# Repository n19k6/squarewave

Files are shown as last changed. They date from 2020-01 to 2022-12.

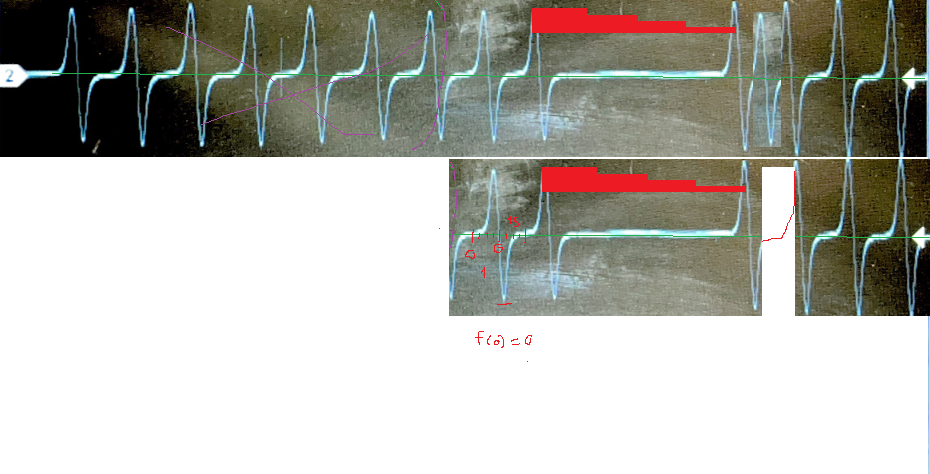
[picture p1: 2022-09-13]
v11_honda_v1/02_signal_synthesis/quadradic_1.png

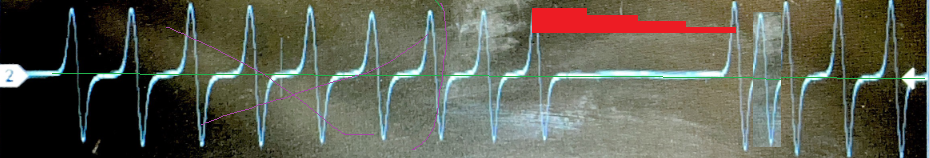
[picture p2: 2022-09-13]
v11_honda_v1/02_signal_synthesis/quadradic_0.png

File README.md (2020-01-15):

# squarewave

This repository contains information about generating squarewave signals using arduino hardware via bit-banging using interrupts.

The original motivation was to simulate a signal generated by a rotational-speed sensor.

The following diagram shows the signal sequence generated by one rotation:

```
 +---+   +---+   +---+   +--     -+   +---+   +---+                  
 |   |   |   |   |   |   |   ...  |   |   |   |   |
 +   +---+   +---+   +---+        +---+   +---+   +---+---+---+---+---

 1       2       3       4            61      62      63      64
```
 
As you can see the signal value high is triggered 62 times followed by a short pause.

The initial requirement was that the signal frequency should be as high as to simulate 7000 rotations measured by the rotational-speed sensor.
We denote this frequency as wheel frequency. Since one rotation generates a signal containing 64 sections the signal frequency is 64 times higher.

The microcontroller ATmega328P contained on the Arduino Nano V3 has three hardware timers capable to generate PWM signals.
But since the signal we want to generate contains a pause at the end of each rotation of the wheel we have to modify the signal PWM signal in some way.
We are using an interrupt to change the signal values 0/1 which is triggered by a hardware timer at the appropriate frequency.
 
Since timer 1 is a 16-bit timer which is counting at 16 Mhz (with prescaler set to 1) it takes 4096 us (4096 microseconds = (1/16 MHz)*2^16) to trigger an overflow.
You can define a compare register to trigger an interrupt if the counter has reached a specific value, i.e. you can trigger at any interval between 1/16 MHz and 4096 us.

Since the calculation and setting of the output pin which is done in an interrupt service routine needs some amount of cpu cylcles the frequency of the interrupts can not be close to 16 MHz.

The calculation of the signal can be done using the following pseudo code using a global volatile byte typed variable count:

```
 +---+   +---+   +---+   +--     -+   +---+   +---+                  
 |   |   |   |   |   |   |   ...  |   |   |   |   |
 +   +---+   +---+   +---+        +---+   +---+   +---+---+---+---+---

 0   1   2   3   4   5   6            120 121 122 123 124 125 126 127

volatile byte count = 0

set counter of timer 1 to 0
if (count % 2 == 0 and count < 124):
  set output to 1
else
  set output to 0
count++
count = count % 128
```

Now the question remains what is the maximum wheel frequency we can achieve, i.e. how much time or cpu cycles does the interrupt service routine use.

If you have a two signal oscilloscope with an appropriate bandwidth, you can measure this by setting a different output pin to 1 at the beginning and 0 at the end of the routine.

We measured that > 160 cpu cycles are necessary. Defining 320 as the minimum for the compare register yields wheel frequencies > 20000 rpm.

## Possible improvements
- FastWrite

## Setup:
If you are using a nano clone with CH340 chip you have to install the driver (see [3]) and use "ATmega328P (Old Bootloader)" as processor within the arduino IDE.

## Structure:
```
README.md - readme (english)
LIESMICH.md - readme (german)
v1_1000_rpm - yields ~ 1000 rpm
v1_maximum - proof of concept that 20000 rpm can be reached
v1_measurement - was used to determine minimum value for compare interrupt
```

Details about timers and interrupts are available at [1].
The used arduino clone "Nano V3.0 CH340" is available at [2].
Install instructions regarding CH320 USB2Serial chip driver are available at [3].

## References:

[1] https://www.heise.de/developer/artikel/Timer-Counter-und-Interrupts-3273309.html (german)

[2] https://www.az-delivery.de/products/nano-v3-0-pro (german)

[3] https://www.makershop.de/ch340-341-usb-installieren/ (german)

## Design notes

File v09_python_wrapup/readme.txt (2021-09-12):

# vim show white spaces
- use commands: set list and set nolist
- to insert a literal tab character use CTRL+V to escape it 
# notepad++ do not replace tab with spaces
- settings -> preferences -> tab settings -> python -> uncheck 'replace by space'

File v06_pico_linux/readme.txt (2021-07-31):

this is an empty file, not exactly it contains in fact two lines
this is line two

let's do it!

https://hackaday.io/project/177817-rp2040-pio-case-study
http://people.ece.cornell.edu/land/courses/ece4760/RP2040/index_rp2040_testing.html

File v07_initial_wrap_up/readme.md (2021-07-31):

# Generating simple waveforms using a raspberry pico and micropython 

(directory location is: v7_initial_wrap_up)

This directory should be used to try to finalize the squarewave project. I.e. more focus on documentation and clean code.

## Requirements

The waveform we want to generate can be thought of being generated by three rotation gears. This might help to memorize the signals we want to generate. The circuit will be used to simulate signals used in the control electronics of a car. The examples given here are generic and can be used to generate arbitrary cyclic signals.

The focus of this write down should be to present how easy it is to generate this signals using a raspberry pico and micropython interaction.

*insert svg here,  IGF, CS, CRKS - camshaft, crankshaft, ignition confirmation signal, Crankshaft Position Sensor (CKP), Camshaft Position Sensor (CMP) todo*

test

Above in the picture you can see three gears. The first gear with a lot of gear tooths can be thought of to generate the *CKP signal* (crankshaft position sensor), the second gear with three gear tooths generates the *CMP signal* (camshaft position sensor) and the third gear with four gear tooths generates the *IGF signal* (ignition confirmation signal). The second and third wheel rotate twice as fast as the first wheel.

You do not have to bother about the abbreviations of the signals - you could also denote the wheels and respective signals A, B, C. Sticking to the abbreviations CKP, CMP and IGF just help me to document my project.

Suppose you put a light sensor at a fixed position that could measure the gear tooths of the rotation wheel passing by. Further on suppose each tooth passing by generates a high signal for 25% and a low signal for 75% of the period of time. So having 34 tooths and 2 gaps in one rotation we can divide the signal corresponding to one rotation into 144 instances in time, e.g. (34+2)\*4. The multiplier corresponds to the 25% percent high state when a tooth passes by. See the following graphical representation:

```
+---+           +---+           +---+           +---+                    +---+           +---+           +---+                                           
|   |           |   |           |   |           |   |            ...     |   |           |   |           |   |                                           
+   +-----------+   +-----------+   +-----------+   +----------       ---+   +-----------+   +-----------+   +-------------------------------------------
0   1   2   3   4   5   6   7   8   9  10  11  12  13  14  15          124 125 126 127 128 129 130 131 132 133 134 135 136 137 138 139 140 141 142 143   
```

The IGF signal generated by the third gear is inverted, i.e. a gear tooth passing by generates a low signal for 25% and a high signal for 75% of the period of time.

## Raspberry Pico Hardware

The raspberry pico has dedicated hardware to accomplish our task. What we use is PIOs () and DMA (?) hardware.
Unfortunately we have to control the DMA hardware by accessing registers directly. There is not API exposed by the rp2 micropython port.

* we construct an array containing the data for all three signals
* we initialize a state machine (PIO) to listen to the FIFO and set the GPIO pins accordingly
* we set up to two DMA channels:
    * the first channel streams the data from  the array to the FIFO of the state machine
    * the second channel is triggered when the first channel has terminated and restarts the first channel again

##  Links

Details about the directory structure:

```
C:.
├─── diagrams/ generate_wheels.py, generate_ascii.py
├─── circuit/ fritzing
├─── source-code/osci
```

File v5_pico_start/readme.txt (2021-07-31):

20210313:

begriffe:

Vx:
alle poties als 32 stellungs poties zu verstehen

V10:
kurbelwelle dreht mit 0,200-20000 U/min 34+2 zacken, duty 25%
nockenwelle 3+4 synchron zu kurbelwelle mit verschiebung
zuendsignal synchron zu kurbelwelle mit verschiebung
zuenaussetzer 1,2,3,4 einzeln komplet aus oder an
wegfahrsperre
zwei lambda sonden signale (=PWM) 0,1 Hz, 1Hz, 10 Hz + duty cyle  = 4 poties

loesungsansaetze:
a) lambda via pwm library
b) andere signale via PIO mit sync oder PIO aus speicher

V11:
zuendaussetzer nicht nur an oder aus sondern aussetzer regelbar von 1/1000 aussetzer bis 1000/1000 aussetzer
frage: per zufall (schwierig?)

V12:
kurbelwelle dreht nicht mit konstanter geschwindigkeit innerhalb einer drehung

###################################

https://www.heise.de/developer/artikel/Ein-Picobello-Microcontroller-Raspberry-Pi-Pico-Board-5045274.html
https://www.cnx-software.com/2021/01/27/a-closer-look-at-raspberry-pi-rp2040-programmable-ios-pio/
https://tutorials-raspberrypi.de/raspberry-pi-pico-mikrocontroller-programmieren/

https://hackspace.raspberrypi.org/articles/what-is-programmable-i-o-on-raspberry-pi-pico
https://www.seeedstudio.com/blog/2021/01/25/programmable-io-with-raspberry-pi-pico/
https://learn.adafruit.com/getting-started-with-raspberry-pi-pico-circuitpython
https://www.cnx-software.com/2021/01/27/a-closer-look-at-raspberry-pi-rp2040-programmable-ios-pio/

MCP3008-I/P

https://www.adafruit.com/product/931
-> nicht verfuegbar
https://shop.pimoroni.com/products/1-12-oled-breakout?variant=29421050757203
-> 14 EUR
https://www.adafruit.com/product/1463
-> 10 EUR
BME280
MPU9250 board
MPU6050 board
-> adafruit 3886-> 7 EUR

Raspberry Pi Pico - USB HID Auto Clicker with Circuit Python

5x2 kabel breadboard 
5x2 femaleXfemale

blues teile breadboard book

20210307:
https://cdn-shop.adafruit.com/datasheets/MCP3008.pdf
https://blog.rareschool.com/2021/02/raspberry-pi-pico-project-2-mcp3008.html

todos:
implement wegfahrsperre
stop and instanciate pio maschine with frequency from poti
research on sync pios, read from memory
document requirements V10+V11+V12
order mcp3008, 10kOhm poties 20, jumper, adapter osci, level shifter ic
#############################
Hi,
I am a PIO beginner. I am exited about the board and got started fast using the good documentation.
I am porting a arduino sketch I programmed month ago for an arduino nano to generate a digital signal using a hardware timer and an ISR.
It did worked but the the hardware was not capable to deliver the signal with the needed frequency, so I thought a good idea to try and get started with the pico.
Especially I like the easy way to do programming with the Thonny IDE, hence no compile cycle or uploading of programs necessary.
My idea is to use micropython for the not time critical parts and use the PIOs for signal generation.

To get started the examples  micropython PIO examples are very valuable: https://github.com/raspberrypi/pico-examples

To understand/use the PIO capabilities it would be great to have two mini examples demonstrating the following:
a) cycle accurate sync of statemachines (see section 3.2.7 Interactions Between State Machines from the rp2040 datasheet: This allows cycle-accurate synchronisation between state machines)
b) reading/consuming data from RAM

The context of my questions is the following: 
I have dump of a signal (on two pins, one clock, one data) that should be triggered if a special input pin goes low (see 20210322c_arduino_reference.png)
I managed to implement the first 25% of the signal with PIO instructions and than reached the mark of 32 instructions, I think with much tinkering I might be able to represent the signal inside the 32 instractions, did only use the X register so far. (see 20210322a.py and 20210322a.png)

Nevertheless if I know/understand cycle-accurate synchronisation between state machines it would be far more straightforward to generate the two synced signals.

Thanks.

Best regards,
Raphael

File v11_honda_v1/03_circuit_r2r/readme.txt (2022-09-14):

dummy

pico: dma 8 outputs using pmod board
check digital outputs first

https://www.hackster.io/56254/using-the-pmod-r2r-with-arduino-uno-ad3de4

0-255 -> 0-3.3V

960 werte pro periode
mem_slot_2[i] = 0b0000_0000_0000_0000_0000_0000_0000_0000
960/4 = 240 32bit words

calculate micropython code for array

-1V = 0, 1V=255

pico+logic analyzer (im keller)

---
pins ansteuern
volt messen (nach wiederstaenden)
ausrechnen (drehzahl 300-mindestens 6.000 besser 10.000)
signal mit oszilaskop messen

---
20220913:
MicroPython v1.16 on 2021-06-18
update to v1.19.1
machine.bootloader()
and copy uf2 file to RPI-RP2
MicroPython v1.19.1 on 2022-06-18

https://vanhunteradams.com/Pico/DAC/DMA_DAC.html
https://forum.micropython.org/viewtopic.php?f=21&t=10717
https://stackoverflow.com/questions/66388451/how-to-use-raspberry-pi-pico-with-dac-with-spi-to-generate-sine-wave-of-1-khz-wi
https://codeutility.org/dma-how-to-use-raspberry-pi-pico-with-dac-with-spi-to-generate-sine-wave-of-1-khz-with-20-k-samples-per-cycle-stack-overflow/
https://people.ece.cornell.edu/land/courses/ece4760/RP2040/index_rp2040_testing.html
https://www.youtube.com/watch?v=OenPIsmKeDI (Raspberry Pi Pico PIO - Ep. 8 - Introduction to DMA)
https://www.youtube.com/watch?v=PrMQpv9iCFw
rp2040-datasheet.pdf DMA section

https://iosoft.blog/2021/10/26/pico-adc-dma/

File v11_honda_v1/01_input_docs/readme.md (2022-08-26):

a)

push: i2s data via dma

https://www.reddit.com/r/raspberrypipico/comments/lcmhs5/got_i2s_dac_working_with_pico/

spi via dma

https://vanhunteradams.com/Pico/DAC/DMA_DAC.html (SPI interface)

https://mcturra2000.wordpress.com/2021/08/09/rp2040-using-dma-to-set-spi-dac-mcp4921/

b)

convert pwm to analog using low filter

https://github.com/romilly/pico-code/blob/master/docs/fungen.md

c) r2r DAC

hardware:

* adafruit circuitpython DAC

https://www.instructables.com/Arbitrary-Wave-Generator-With-the-Raspberry-Pi-Pic/

https://learn.adafruit.com/mcp4725-12-bit-dac-tutorial

https://www.hackster.io/news/learn-how-to-use-pwm-to-generate-an-audio-signal-from-your-raspberry-pi-pico-00347dece8b8

https://github.com/rgrosset/pico-pwm-audio

https://datasheets.raspberrypi.com/rp2040/hardware-design-with-rp2040.pdf#page=24

https://datasheets.raspberrypi.com/rp2040/hardware-design-with-rp2040.pdf#page=24

a) Resistor DAC

https://datasheets.raspberrypi.com/rp2040/hardware-design-with-rp2040.pdf#page=24 (3.2.1. Resistor DAC)

https://digilent.com/reference/_media/reference/pmod/pmodr2r/pmodr2r_sch.pdf

b) Low Passfilter (PWM -> Analog)

https://github.com/romilly/pico-code/blob/master/docs/fungen.md

c) Dedicated DAC

https://datasheets.raspberrypi.com/rp2040/hardware-design-with-rp2040.pdf#page=24 (3.4.2. PCM(I2S audio, PCM5101A) [PCM]

https://github.com/miketeachman/micropython-i2s-examples (I2S DAC)

https://github.com/romilly/pico-code/blob/master/src/pico_code/pico/experiments/pio_dac.py

http://blog.rareschool.com/2021/02/raspberry-pi-pico-simple-projects.html

d) DMA

https://iosoft.blog/category/dma/

Kaufen (boards):

Berrybase:

Adafruit MCP4725 Breakout Board - 12-Bit DAC mit I2C Interface

MCP4725

5,10

12-Bit

I2C

Kaufen (ics):

Hardware:

Pmod R2R: Resistor Ladder D/A Converter, digilent

https://circuitdigest.com/tags/mcp4725

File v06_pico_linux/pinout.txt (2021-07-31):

Anforderungen:
--------------
raspberry picohat durchnummerierte pins von P1-P40 + 3 debug pins 

folgende pins werden benötigt:
SPI+GPIO für ADC (MCP3008)
SPI+GPIO für zweiten ABC (optional)

RESET Pin über Jumper zugänglich machen, als reset schalter
https://www.raspberrypi.org/blog/how-to-add-a-reset-button-to-your-raspberry-pi-pico/
P38 (GND) mit P30 (RUN) über jumper rausführen

4 GPIO eingänge für IGF1-IGF4

4 Zusamenhängende GPIOs für CS, IGF und CRK
IGF ist das signal von den Zündspulen. CS ist Camshaft, Nockenwelle. CRK ist Crankshaft, Kurbelwelle

2 GPIO für LAmmda Signale

2 GPIO herausführen zum debuging von signalen
2 UART Pins für debugging

Pinout:
-------
P1-P2 zum debuging als pin (d.h. nur loch auf platine herausführen)
P3 zum debuging als pin herausführen

P4-P6 für MCP3008 (A)
P19 für MCP3008-CS (A)

P14-P16 für MCP3008 (B=optionaler zweiter MCP3008)
P19 für MCP3008-CS (B=optionaler zweiter MCP3008)

P21 für Ausgangssignal Lambda1
P22 für Ausgangssignal Lambda2

P24 für Ausgangssignal CRK
P25 für Ausgangssignal CS
P26 für Ausgangssignal IGF
P27 für Ausgangssignal: Debugging signal frequenz Kurbelwelle

P30 über jumper mit GND verbindbar machen für reset

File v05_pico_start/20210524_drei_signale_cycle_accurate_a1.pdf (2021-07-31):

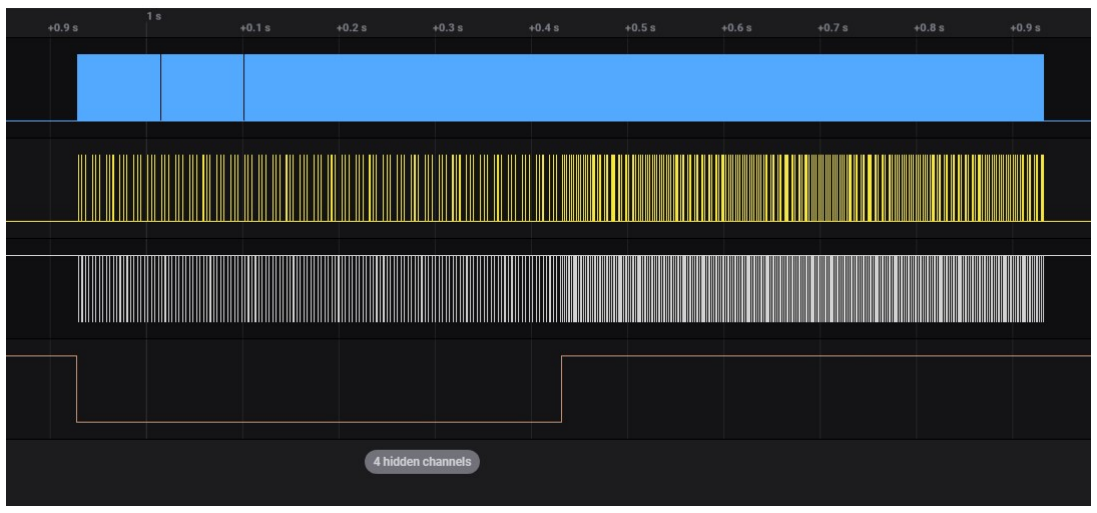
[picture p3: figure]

signals are shifted by:
d = 4
d2 = 5
d3 = 0

sm = rp2.StateMachine(1, nockenwelle, freq=1_0_000, set_base=Pin(18))
sm2 = rp2.StateMachine(0, zuendsignal2, freq=1_0_000, set_base=Pin(17))
sm3 = rp2.StateMachine(2, kurbelwelle, freq=1_0_000, set_base=Pin(19))

first half of second is 10kHz second half is 20 kHz

1

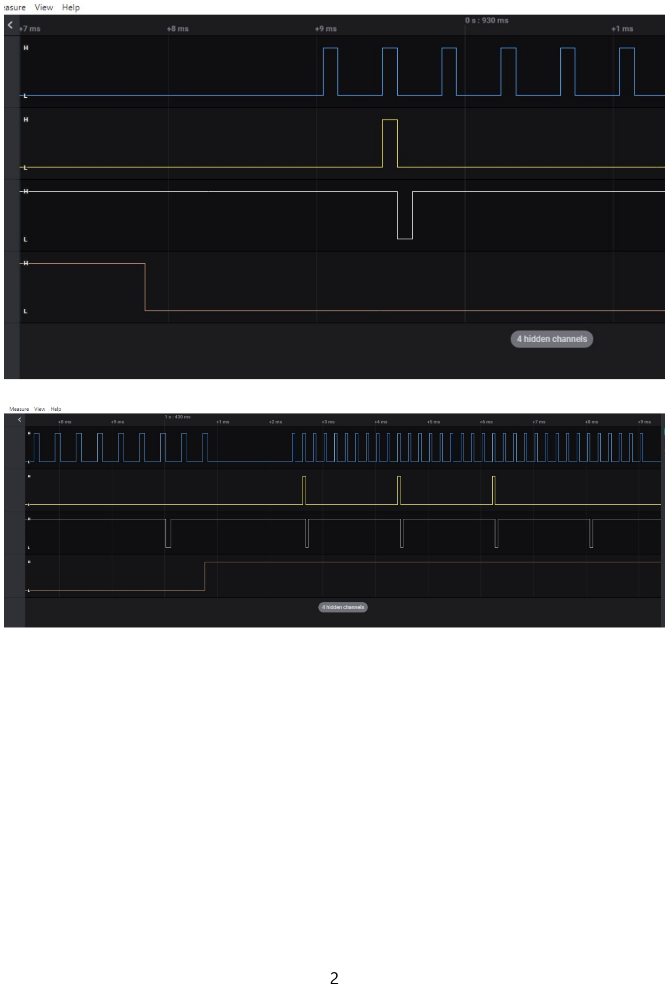
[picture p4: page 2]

2

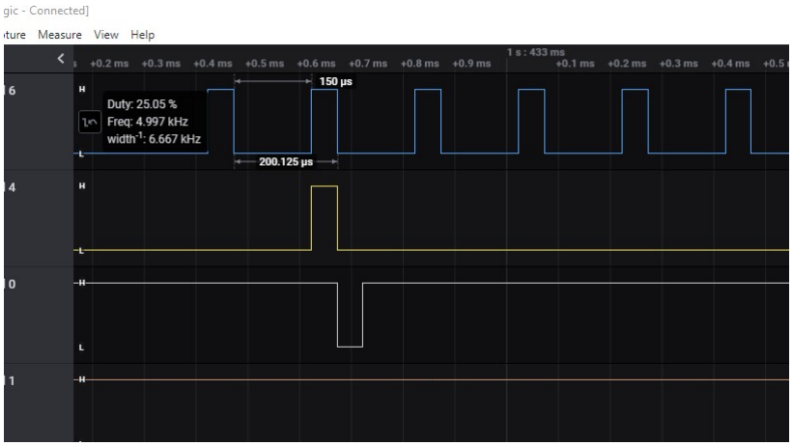
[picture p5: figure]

3

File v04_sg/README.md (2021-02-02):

drei digitale signale

- kurbelwellen signal 150 Umdrehngen bis 5000 Umdrehungen
- scheibe mit 34 zacken 2 leer, pro 10 grad eine markierung 25, 75 leer (10 bit)

 - nockenwellen signal
 - 3/4 zacken sind besetzt einer fehlt
 - kurbelwelle dreht doppel so schnell wie nockenwelle
 - 2 potentiometer
 - 0-360
 
 - zündreferenzsignal, phasen verschiebung bzgl kurbelwelle
 - potis 10kOhm
 - 1 umdrehung pro sekunde, nach strom, 100 umdrehung
 
 20210123: new try (alles einfach, ohne optimierungen, brute-force)
 - a) sketch machen der schnelles rechteck signal erzeugt (potenziell nicht schneller als 20-100 cpu takt zykel)
 - b) sketch machen der parallel poti werte ausliest und auf der werte auf seriellen schnittstelle dumpt
 - c) anpassung von a) auf kurbelwellen signal (34 zacken, 2 leer, 50% duty cycle)
 - d) steuerung der umdrehungen der kurbelwelle via poti 1. 6000 Umdrehungen können wegen geringem CPU takt von 8 MHz wahrscheinlich nicht erreicht werden

neues signal für lambda sonde:
0.1Hz-1Hz-10Hz
duty cycle 0%-100%, Mittelstellung ist 50%
duty cycle<5% = always low
duty cycle>95& = always high

poti 1: kurbelwelle, poti 2: lambda sonde frequenz, poti 3: lambda sonde duty cycle

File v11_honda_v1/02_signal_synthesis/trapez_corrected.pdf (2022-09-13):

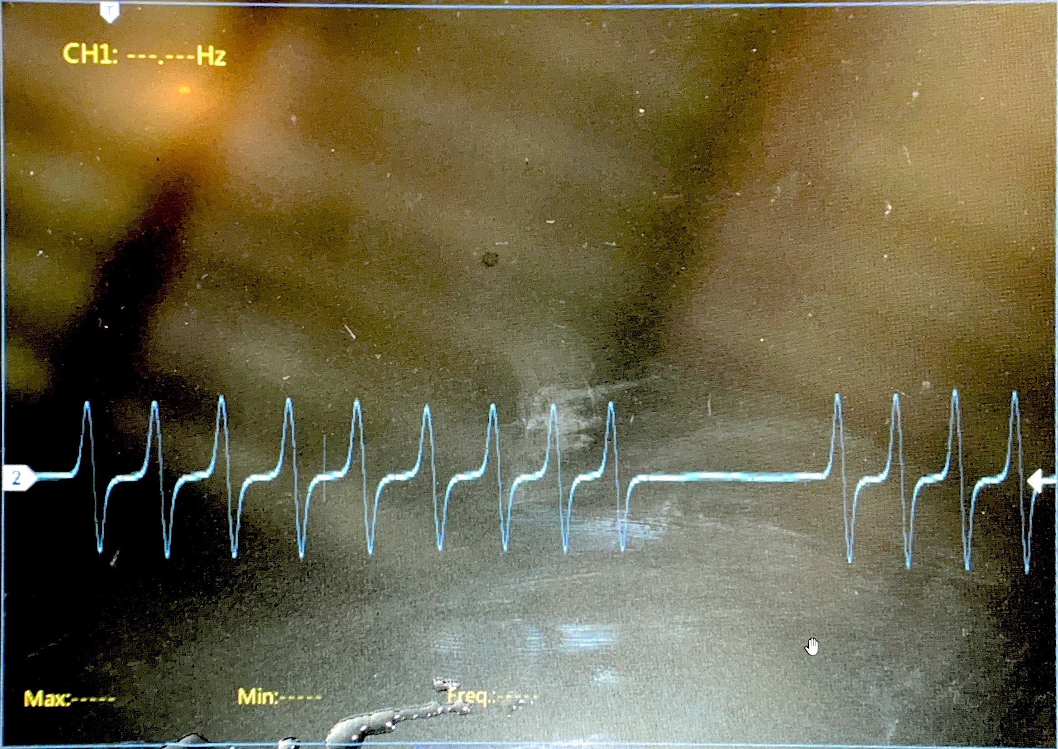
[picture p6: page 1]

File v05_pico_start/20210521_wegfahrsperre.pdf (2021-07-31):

20210521_wegfahrsperre.py

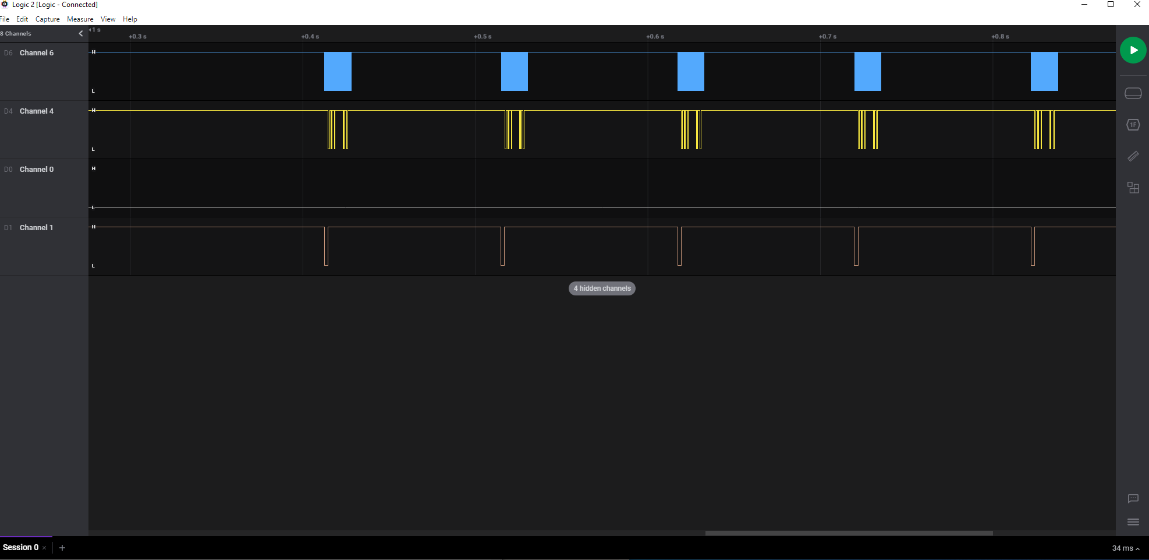
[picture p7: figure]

Channel 1 ist das trigger signal. Channel 4 die daten, channel 6 der takt

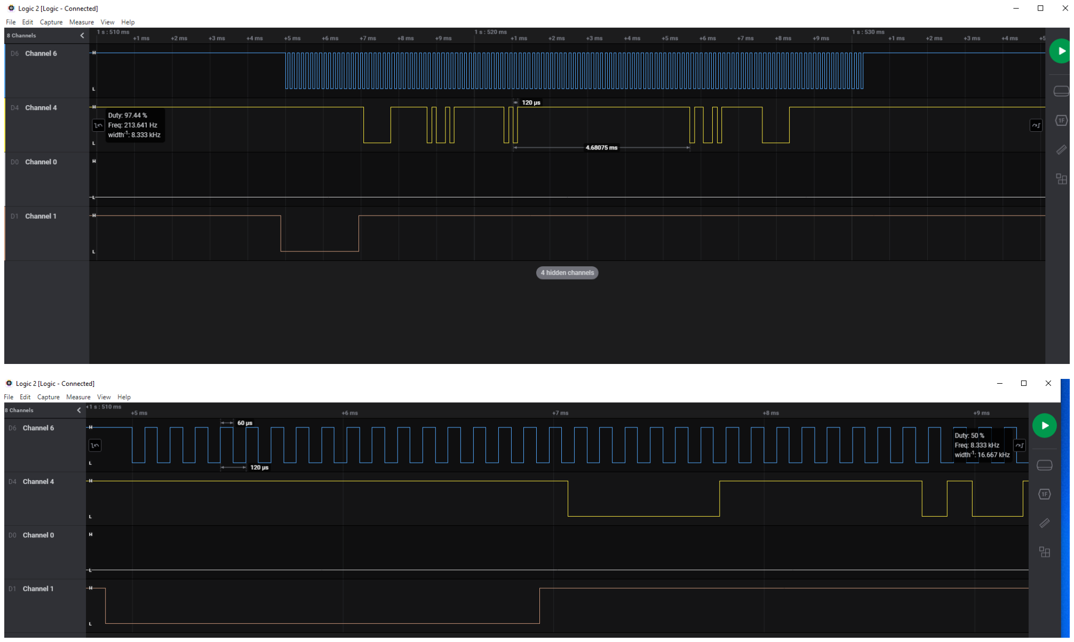
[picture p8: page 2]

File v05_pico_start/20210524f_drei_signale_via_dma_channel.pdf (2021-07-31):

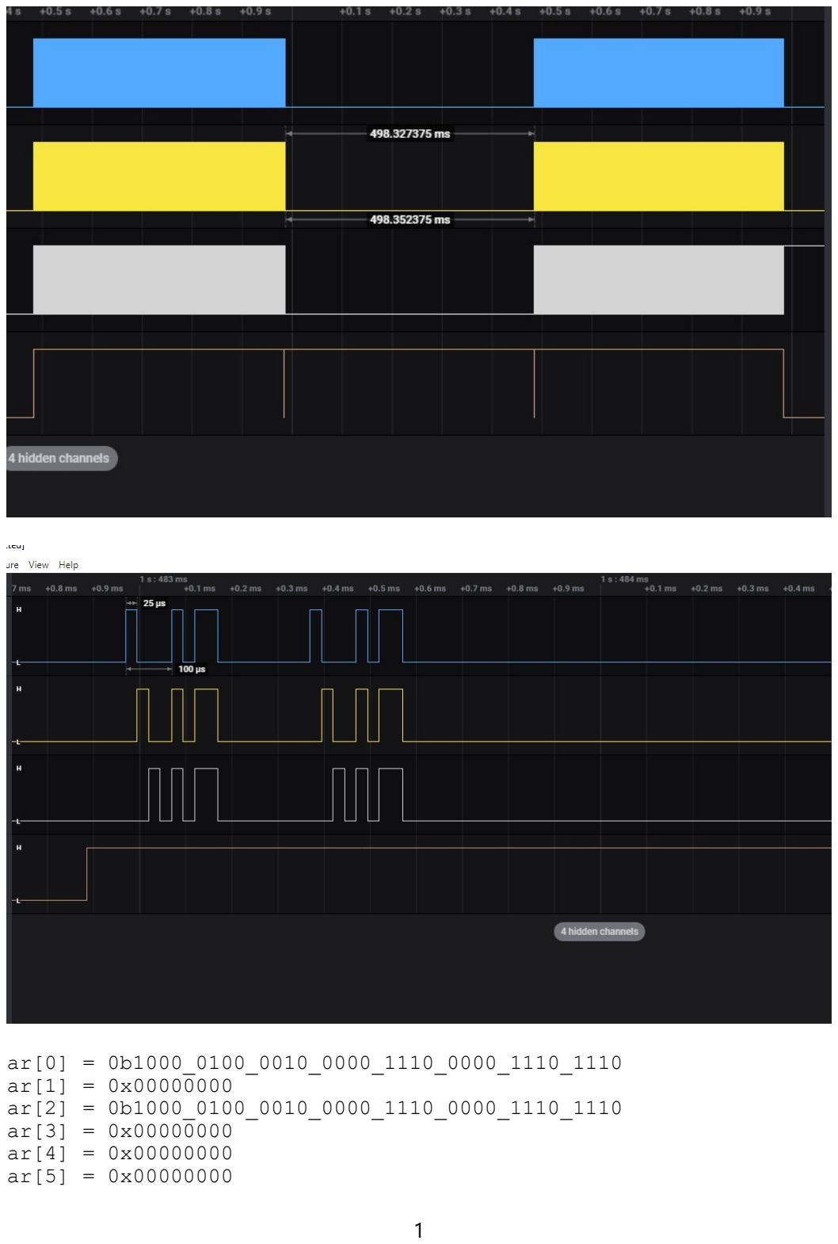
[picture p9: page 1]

ar[0] = 0b1000_0100_0010_0000_1110_0000_1110_1110 ar[1] = 0x00000000
ar[2] = 0b1000_0100_0010_0000_1110_0000_1110_1110 ar[3] = 0x00000000
ar[4] = 0x00000000
ar[5] = 0x00000000

1

ar[6] = 0x00000000
ar[7] = 0x00000000
ar[8] = 0x00000000
ar[9] = 0b0000_0000_0000_0000_1110_0000_1110_0000

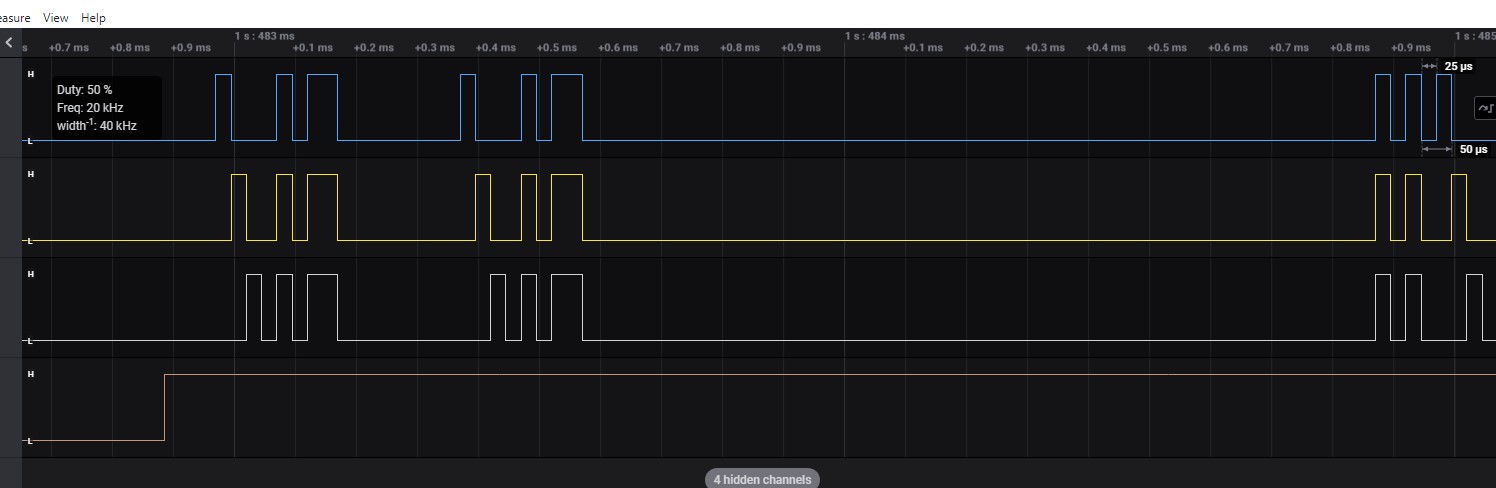
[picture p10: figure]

2

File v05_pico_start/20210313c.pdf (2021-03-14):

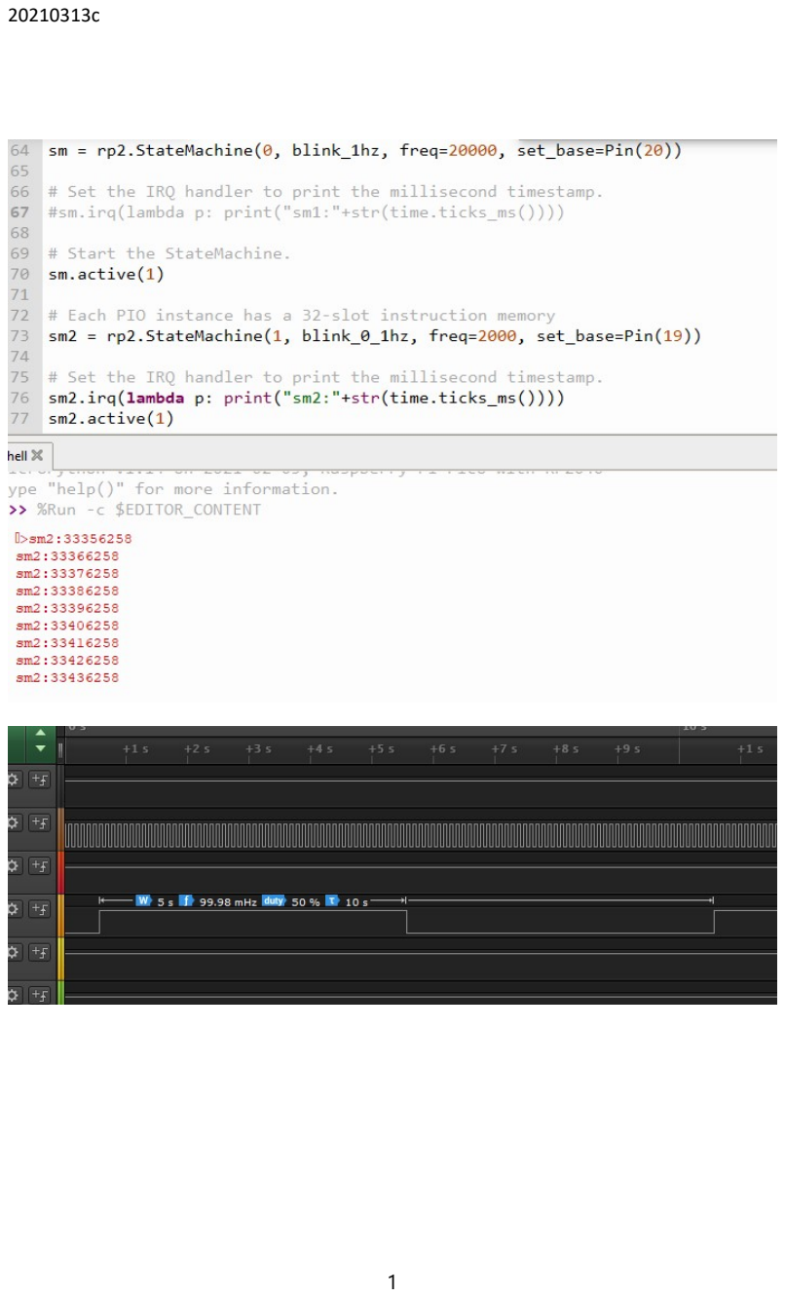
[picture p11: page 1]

20210313c

1

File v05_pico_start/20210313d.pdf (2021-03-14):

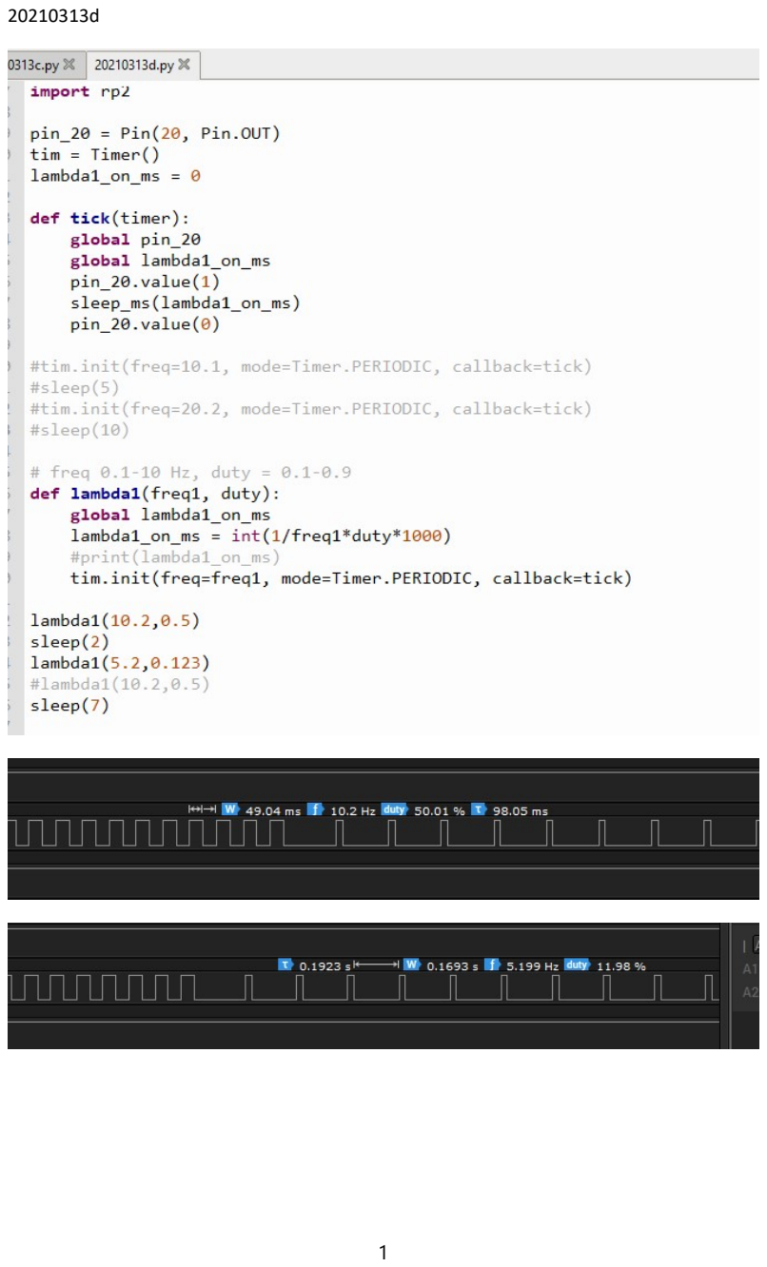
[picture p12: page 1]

20210313d

1

2

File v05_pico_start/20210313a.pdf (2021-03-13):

20210313a

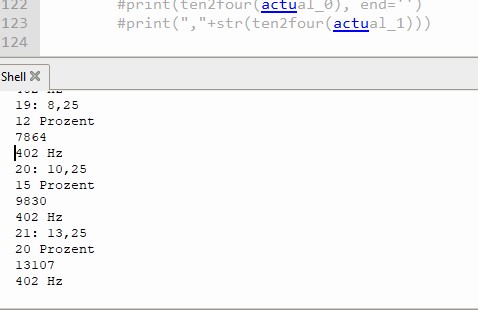
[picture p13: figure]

1

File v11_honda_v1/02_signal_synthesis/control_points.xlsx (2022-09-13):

peak-high |  | null-durchgang
71 | #VALUE! | 464 | #VALUE!
131 | 60 | 490 | 26
190 | 59 | 515 | 25
250 | 60 | 540 | 25
310 | 60 | 566 | 26
372 | 62 | 715 | 149
430 | 58 | 740 | 25
483 | 53 | 766 | 26
534 | 51 | 791 | 25
734 | 200 | 818 | 27
786 | 52 | 845 | 27
838 | 52 | 871 | 26
891 | 53 | 897 | 26

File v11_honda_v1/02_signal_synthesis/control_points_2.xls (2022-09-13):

peak-high |  |  | null-durchgang
71 | #VALUE! |  | 464 | #VALUE!
131 | 60 |  | 490 | 26
190 | 59 |  | 515 | 25
250 | 60 |  | 540 | 25
310 | 60 |  | 566 | 26
372 | 62 |  | 715 | 149
430 | 58 |  | 740 | 25
483 | 53 |  | 766 | 26
534 | 51 |  | 791 | 25
734 | 200 |  | 818 | 27
786 | 52 |  | 845 | 27
838 | 52 |  | 871 | 26
891 | 53 |  | 897 | 26
x | f(x) | f'(x)
0 | 0 | 0
3.75 | 0 | 0
7.5 | 0 | 0.02
11.25 | 1 | 0
15 | 0 | -2.6
18.75 | -1 | 0
22.5 | 0 | 0.02
26.25 | 0 | 0
30 | 0
33.75 | 0
37.5 | 0
41.25 | 1
45 | 0
48.75 | -1
52.5 | 0
56.25 | 0
60 | 0
63.75 | 0
67.5 | 0
71.25 | 1
75 | 0
78.75 | -1
82.5 | 0
86.25 | 0
90 | 0
93.75 | 0
97.5 | 0
101.25 | 1
105 | 0
108.75 | -1
112.5 | 0
116.25 | 0
120 | 0
123.75 | 0
127.5 | 0
131.25 | 1
135 | 0
138.75 | -1
142.5 | 0
146.25 | 0
150 | 0
153.75 | 0
157.5 | 0
161.25 | 1
165 | 0
168.75 | -1
172.5 | 0
176.25 | 0
180 | 0
183.75 | 0
187.5 | 0
191.25 | 1
195 | 0
198.75 | -1
202.5 | 0
206.25 | 0
210 | 0
213.75 | 0
217.5 | 0
221.25 | 1
225 | 0
228.75 | -1
232.5 | 0
236.25 | 0
240 | 0
243.75 | 0
247.5 | 0
251.25 | 1
255 | 0
258.75 | -1
262.5 | 0
266.25 | 0
270 | 0
273.75 | 0
277.5 | 0
281.25 | 0
285 | 0
288.75 | 0
292.5 | 0
296.25 | 0
300 | 0
303.75 | 0
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

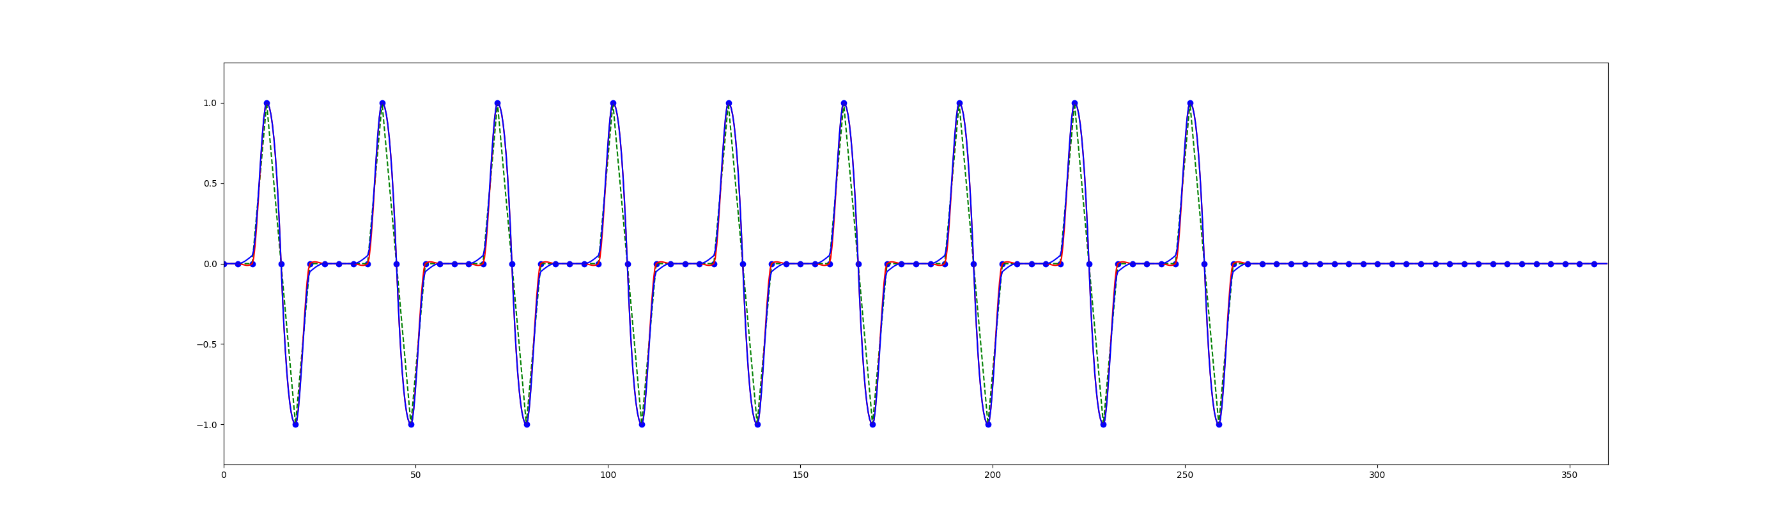
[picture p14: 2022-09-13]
v11_honda_v1/02_signal_synthesis/out_quadratic.png

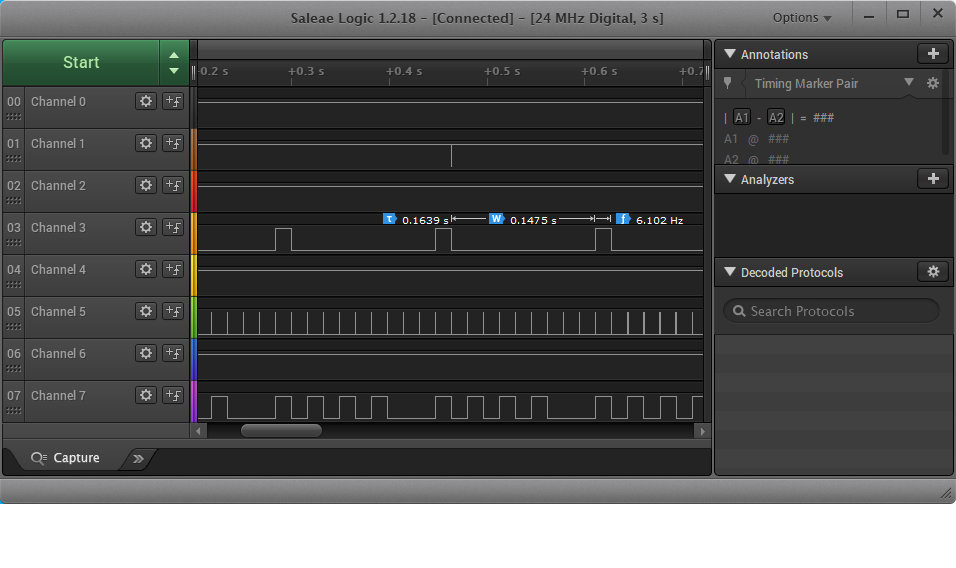
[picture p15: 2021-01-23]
v04_sg/sketch_20210123d_255.png

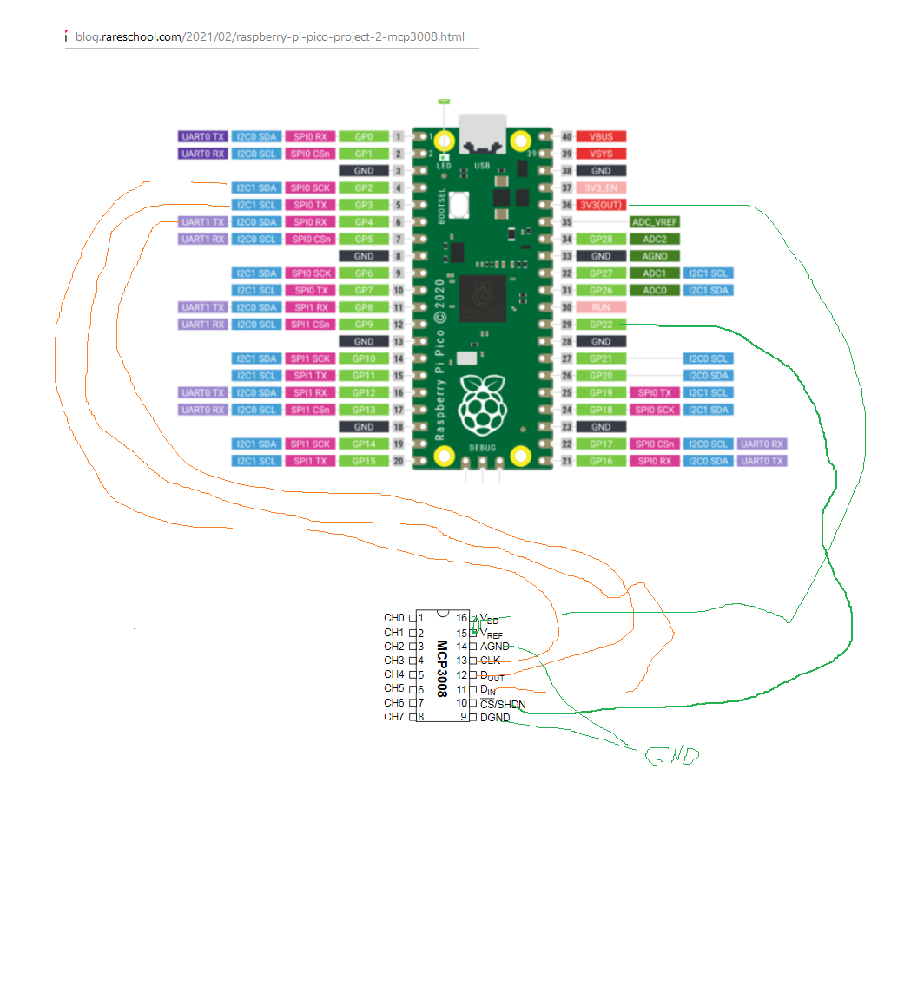
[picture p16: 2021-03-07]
v05_pico_start/20210307_mcp3008.png

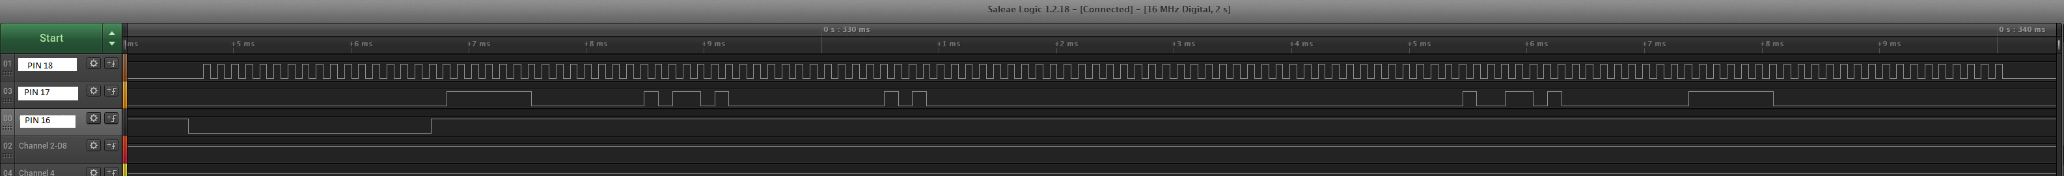
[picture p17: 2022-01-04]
v10_prototype_version_2/20220103/20210521_wegfahrsperre_004.png

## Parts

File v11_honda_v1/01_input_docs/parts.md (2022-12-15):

Component | Type | Manufacturer | Mouserpart-Nr | Productpage | Datasheet
--------       | --------  | -------- | -------- | --------| --------
R2R ladder     | PmodR2R   | Digilent | 485-239  | [R2R ladder](https://digilent.com/shop/pmod-r2r-resistor-ladder-d-a-converter/) | [Schematic](https://digilent.com/reference/_media/reference/pmod/pmodr2r/pmodr2r_sch.pdf)
DAC    | DAC0808LCN/NOP | TI   | [926-DAC0808LCN/NOPB](https://www.mouser.de/ProductDetail/Texas-Instruments/DAC0808LCN-NOPB?qs=7X5t%252BdzoRHDv8TW%252BETgvcg%3D%3D) | - | -
Dual 10bit DAC w/SPI     | MCP4812-E/P   | Microchip | [579-MCP4812-E/P](https://www.mouser.de/ProductDetail/Microchip-Technology-Atmel/MCP4812-E-P?qs=bxUt0k7cytI17caZuUAwlA%3D%3D)  | -| -
Dual 8bit DAC w/SPI     | MCP4802-E/P   | Microchip | [579-MCP4802-E/P](https://www.mouser.de/ProductDetail/Microchip-Technology-Atmel/MCP4802-E-P?qs=bxUt0k7cytI0U0E3kiOWig%3D%3D)  | -| -
MCP4725 Breakout     | MCP4725 | Adafruit | [485-935](https://www.mouser.de/ProductDetail/Adafruit/935?qs=GURawfaeGuDLSBaw80Z3Sg%3D%3D)  | [MCP4725 Breakout](https://www.adafruit.com/product/935)| [Datasheet](https://cdn-shop.adafruit.com/datasheets/mcp4725.pdf)

Raspberry Pico Datasheets (expecially Pi Pico):
[Documentation](https://www.raspberrypi.com/documentation/microcontrollers/raspberry-pi-pico.html)

Possible next steps:
- use R2R ladder and generate sine-wave using DMA on pico
  - how to connect Pmod R2R with pico (schematics)
  - how to meassure voltage with osciloscope
- connect one of the ics using an interface like i2c or spi
  - DAC0808LCN/NOP might be similiar to r2r ladder circuit

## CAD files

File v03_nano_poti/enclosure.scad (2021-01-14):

$fn=30;

difference(){
    base();
    union() {
        translate([(70-45.5)/2,20])
        square([45.5,35]);
    }
    translate([15,75])
    poti();
    translate([35,75])
    poti();
    translate([55,75])
    poti();
}

translate([(70-45.2)/2,20+0.15])
square([45.2,5]);
translate([(70-45.2)/2,50-0.15])
square([45.2,5]);

translate([-20,0])
square([10,10]);

translate([-40,5])
difference() {
    circle(5);
    circle(2);
}


module base() {
    difference() {
        union() {
            difference() {
                square([70,100]);
                square([10,10]);
                translate([0,90])
                square([10,10]);
                translate([60,90])
                square([10,10]);
                translate([60,0])
                square([10,10]);
            }
            translate([10,10])
            circle(10);
            translate([10,90])
            circle(10);
            translate([60,90])
            circle(10);
            translate([60,10])
            circle(10);
        }
            translate([10,10])
            circle(2);
            translate([10,90])
            circle(2);
            translate([60,90])
            circle(2);
            translate([60,10])
            circle(2);       
    }
}

module poti() {
    circle(6.2/2);
    translate([-11+6.2/2,0])
    square([0.5,2],true);
}
        

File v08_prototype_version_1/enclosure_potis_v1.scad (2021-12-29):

// attention: holes and squares for poties are to small

$fn=30;

translate([80,-130])
difference(){
    base_potis();
    union() {
        //translate([(70-45.5)/2,20])
        //square([45.5,35]);
        //translate([(70-45.2)/2,20+0.15])
        //square([45.2,5]);
        //translate([(70-45.2)/2,50-0.15])
        //square([45.2,5]);
    }
    translate([50,25]) {
        translate([-27,75])
        poti();
        translate([-9,75])
        poti();
        translate([9,75])
        poti();
        translate([27,75])
        poti();
    }
    translate([50,-55]) {
        translate([-27,75])
        rotate(180)
        poti();
        translate([-9,75])
        rotate(180)
        poti();
        translate([9,75])
        rotate(180)
        poti();
        translate([27,75])
        rotate(180)
        poti();
    }
}


translate([80,0])
difference(){
    base();
    union() {
        //translate([(70-45.5)/2,20])
        //square([45.5,35]);
        translate([(70-45.2)/2,20+0.15])
        square([45.2,5]);
        translate([(70-45.2)/2,50-0.15])
        square([45.2,5]);
    }
    translate([15,75])
    poti();
    translate([35,75])
    poti();
    translate([55,75])
    poti();
}

difference(){
    base();
    union() {
        translate([(70-45.5)/2,20])
        square([45.5,35]);
    }
    //translate([15,75])
    //poti();
    //translate([35,75])
    //poti();
    //translate([55,75])
    //poti();
}

//translate([(70-45.2)/2,20+0.15])
//square([45.2,5]);
//translate([(70-45.2)/2,50-0.15])
//square([45.2,5]);

translate([-20,0])
square([10,10]);

translate([-40,5])
difference() {
    circle(5);
    circle(2);
}

translate([-80,20])
difference() {
    union() {
        translate([35,10])
        square([50,10],true);
        translate([10,10])
        circle(5);
        translate([60,10])
        circle(5);
    }
    translate([10,10])
    circle(2);
    translate([60,10])
    circle(2);
}

translate([80,-150])
difference() {
    union() {
        translate([35+15,10])
        square([50+30,10],true);
        translate([10,10])
        circle(5);
        translate([60+30,10])
        circle(5);
    }
    translate([10,10])
    circle(2);
    translate([60+30,10])
    circle(2);
}

module base() {
    difference() {
        union() {
            difference() {
                square([70,100]);
                square([10,10]);
                translate([0,90])
                square([10,10]);
                translate([60,90])
                square([10,10]);
                translate([60,0])
                square([10,10]);
            }
            translate([10,10])
            circle(10);
            translate([10,90])
            circle(10);
            translate([60,90])
            circle(10);
            translate([60,10])
            circle(10);
        }
            translate([10,10])
            circle(2);
            translate([10,90])
            circle(2);
            translate([60,90])
            circle(2);
            translate([60,10])
            circle(2);       
    }
}

module base_potis() {
    difference() {
        union() {
            difference() {
                square([100,120]);
                square([10,10]);
                translate([0,110])
                square([10,10]);
                translate([90,110])
                square([10,10]);
                translate([90,0])
                square([10,10]);
            }
            translate([10,10])
            circle(10);
            translate([10,110])
            circle(10);
            translate([90,110])
            circle(10);
            translate([90,10])
            circle(10);
        }
            r1=2;
            translate([10,10])
            circle(r1);
            translate([10,110])
            circle(r1);
            translate([10,60])
            circle(2);
            translate([90,60])
            circle(2);
            translate([90,110])
            circle(r1);
            translate([90,10])
            circle(r1);
    }
}

module poti() {
    circle(6.2/2);
    //circle(8);
    translate([-11+6.2/2,0])
    square([0.5,2],true);
}
        

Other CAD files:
v03_nano_poti/enclosure_v2.scad

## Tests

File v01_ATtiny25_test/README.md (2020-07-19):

# v1_ATtiny25_test

programming an ATtiny25 using AVR-PROG (www.diamex.de)

use 

[1] https://franzi.hamburg/arduino/bootloader-brennen.html (german)
[2] https://create.arduino.cc/projecthub/john-bradnam/using-the-new-attiny-processors-with-arduino-ide-612185

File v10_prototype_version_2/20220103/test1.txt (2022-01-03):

https://www.teamviewer.com/de/download/previous-versions/
TeamViewer Portable
TeamViewerPortable.zip

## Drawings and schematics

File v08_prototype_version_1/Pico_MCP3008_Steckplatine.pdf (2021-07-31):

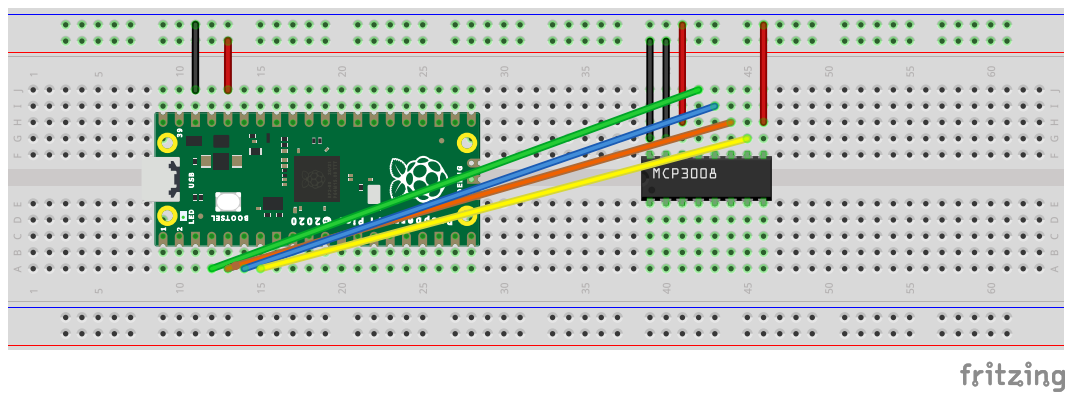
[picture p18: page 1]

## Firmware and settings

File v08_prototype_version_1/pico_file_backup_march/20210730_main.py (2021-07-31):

#https://github.com/hoihu/projects/blob/master/pico/dma.py


# 20.000 U/min = 333 U/s ~ 3 ms
# 
from rp2 import PIO, StateMachine, asm_pio
from machine import Pin, mem32
from time import sleep
from array import array

from uctypes import BF_POS, BF_LEN, BFUINT32, UINT32, struct, addressof

PIO0_BASE = 0x50200000
PIO0_BASE_TXF0 = PIO0_BASE+0x10
CH0_READ_ADDR = 0x50000000+0x00

DMA_CTRL_REG = {
        "AHB_ERROR": 31     << BF_POS | 1 << BF_LEN | BFUINT32,
        "READ_ERR": 30      << BF_POS | 1 << BF_LEN | BFUINT32,
        "WRITE_ERR": 29     << BF_POS | 1 << BF_LEN | BFUINT32,
        "Reserved": 25      << BF_POS | 4 << BF_LEN | BFUINT32,
        "BUSY": 24          << BF_POS | 1 << BF_LEN | BFUINT32,
        "SNIFF_EN": 23      << BF_POS | 1 << BF_LEN | BFUINT32,
        "BSWAP": 22         << BF_POS | 1 << BF_LEN | BFUINT32,
        "IRQ_QUIET": 21     << BF_POS | 1 << BF_LEN | BFUINT32,
        "TREQ_SEL": 15      << BF_POS | 6 << BF_LEN | BFUINT32,
        "CHAIN_TO": 11      << BF_POS | 4 << BF_LEN | BFUINT32,
        "RING_SEL": 10      << BF_POS | 1 << BF_LEN | BFUINT32,
        "RING_SIZE": 6      << BF_POS | 4 << BF_LEN | BFUINT32,
        "INCR_WRITE": 5     << BF_POS | 1 << BF_LEN | BFUINT32,
        "INCR_READ": 4      << BF_POS | 1 << BF_LEN | BFUINT32,
        "DATA_SIZE": 2      << BF_POS | 2 << BF_LEN | BFUINT32,
        "HIGH_PRIO": 1      << BF_POS | 1 << BF_LEN | BFUINT32,
        "EN": 0             << BF_POS | 1 << BF_LEN | BFUINT32,
}

DMA_LAYOUT = {
    "READ_ADDR": 0   | UINT32,
    "WRITE_ADDR": 4  | UINT32,
    "TRANS_COUNT": 8 | UINT32,
    "CTRL_TRIG": (12,  DMA_CTRL_REG),
    "CTRL_TRIG_RAW": 12 | UINT32, # for single update of all fields
    "AL1_CTRL": 16   | UINT32,
    "ABORT": 1092 | UINT32,
}

# create the DMA channel structs (0-11)
CHANNELS = [struct(0x50000000 + i * 0x40, DMA_LAYOUT) for i in range(0,12)]

# init dma channels to some default values
def init_channels():
    for i, ch in enumerate(CHANNELS):
        # no wraparound, sniff=0, swap_byte=0, irq_quiet=1
        # unpaced transfers (=0x3f). high prio=0, data_size=word, incr_r/w = true
        ch.CTRL_TRIG_RAW = 0x3f8030
        # set chain to itself, to disable chaining
        ch.CTRL_TRIG.CHAIN_TO = i

# example function to show mem->mem transfer
# dest, src can be bytearrays, size in bytes
def memcopy(ch, dest, src, size, enable=1):
    ch.CTRL_TRIG.EN = 0
    ch.WRITE_ADDR = addressof(dest)
    ch.READ_ADDR = addressof(src)
    ch.TRANS_COUNT = size // (1 << ch.CTRL_TRIG.DATA_SIZE)
    ch.CTRL_TRIG.EN = enable


init_channels()

'''
a = bytearray(100)
b = bytearray(100)

print("Before: b={}".format(b))
# copy some stuff to a
for i in range(0,100):
    a[i] = i

# copy a -> b using dma channel 0
memcopy(CHANNELS[0], b, a, 100)

print("After: b={}".format(b))
'''

# 288*4/32 = 36
data = array("I", [0 for _ in range(36)])

#

offset_n = 4
offset_z = 5

def fill_array(n, z, z1=True, z2=True, z3=True, z4=True):
    
    a = array("I", [0 for _ in range(36)])
    a[0] = a[0] | 1<<31

    for i in range(288*4):
        if i%4 == 0 and i%8 == 0: 
            #i = i*4+1
            #j, k = int(i/32), i % 32
            j = int(i/32)
            k = i % 32
            #a[j] = a[j] | 1<<31-k
            
    for i in range(34):
        i = i*4*4+3
        #j, k = int(i/32), i % 32
        j = int(i/32)
        k = i % 32
        a[j] = a[j] | 1<<31-k

    for i in range(34):
        i = 144*4+i*4*4+3
        #j, k = int(i/32), i % 32  ggg
        j = int(i/32)
        k = i % 32
        #print(j)
        a[j] = a[j] | 1<<31-k

    for i in range(288):
        i = i*4+2
        #j, k = int(i/32), i % 32
        j = int(i/32)
        k = i % 32
        a[j] = a[j] | 1<<31-k
        

    for i in range(4):
        za=[z1,z2,z3,z4]
        if za[i]:
            i = i*72*4+2+z*4
            i = i % (288*4)
            #j, k = int(i/32), i % 32
            j = int(i/32)
            k = i % 32
            #print(j)
            #a[j] = a[j] | 1<<31-k
            a[j] = a[j] & ~(1<<31-k)
            
    for i in range(288):
        i = i*4+1
        #j, k = int(i/32), i % 32
        j = int(i/32)
        k = i % 32
        #printdef fill_array(n, z, z1=True, z2=True, z3=True, z4=True):
        #a[j] = a[j] | 1<<31-k

    for i in range(3):
        i = i*72*4+1+n*4
        #j, k = int(i/32), i % 32
        i = i % (288*4)
        j = int(i/32)
        k = i % 32
        #print(j)
        #a[j] = a[j] & ~(1<<31-k)
        #a[j] = a[j] & ~(1<<31-k)
        a[j] = a[j] | 1<<31-k               
    return a


offset_n = 0
offset_z = 0

data = fill_array(offset_n, offset_z, False, True, True, True)
data2 = fill_array(-1, -2, True, True, False, True)

print(addressof(data))
print(addressof(data2))

print(bin(data[0]))
print(bin(data2[0]))



#for i in range(36*2):
#    if i!=35 and i!=36 and i!=71 and i!=72: 
#        i = i*4+1
#        #j, k = int(i/32), i % 32
#        j = int(i/32)
#        k = i % 32
#        #data[j] = data[j] | 1<<31-k

#for i in range(3):
#    j, k = int((i*3*72+1)/32), (i*3*72+1) % 32
#    #data[j] = data[j] | 1<<31-k
    
#for i in range(4):
#    j, k = int((i*3*72+2)/32), (i*3*72+2) % 32
#    #data[j] = data[j] | 1<<31-k

#data[0] = 0b1000_0000_1000_0000_1000_0000_1000_0000
#data[1] = 0b1000_0000_0000_0000_0000_0000_0000_0000
#data[2] = 0b1000_0000_0000_0000_0000_0000_0000_0000
#data[3] = 0b1000_0000_0000_0000_0000_0000_0000_0000
#data[4] = 0b1000_0000_0000_0000_0000_0000_0000_0000

print("calc done")

#print(bin(8 | UINT32))

ar = array("I", [0 for _ in range(96)])
#ar[0] = 0b100_010_001_000_111_000_000_000_000_000_00
ar[0] = 0b1111_0100_0010_0000_1110_0000_1110_1110
ar[1] = 0x00000000
ar[2] = 0b1000_0100_0010_0000_1110_0000_1110_1110
ar[3] = 0x00000000
ar[4] = 0x00000000
ar[5] = 0x00000000
ar[6] = 0x00000000
ar[7] = 0x00000000
ar[8] = 0x00000000
ar[9] = 0b0000_0000_0000_0000_1110_0000_1110_0000
#ar[2] = 0xaa00aa00

ar_p = array("I", [0])
ar_p[0] = addressof(data)

ar2 = array("I", [0 for _ in range(10)])
#ar[0] = 0b100_010_001_000_111_000_000_000_000_000_00
ar2[0] = 0b0010_0100_1000_0000_1110_0000_1110_1110
ar2[1] = 0x00000000
ar2[2] = 0b0010_0100_1000_0000_1110_0000_1110_1110
ar2[3] = 0x00000000
ar2[4] = 0x00000000
ar2[5] = 0x00000000
ar2[6] = 0x00000000
ar2[7] = 0x00000000
ar2[8] = 0x00000000
ar2[9] = 0b0000_0000_0000_0000_1110_0000_1110_0000

@rp2.asm_pio(
    # zuendung, nockewelle, kurbelwelle, debug gggdfdf
    #out_init=(rp2.PIO.OUT_HIGH, rp2.PIO.OUT_LOW, rp2.PIO.OUT_LOW, rp2.PIO.OUT_LOW),
    out_init=(rp2.PIO.OUT_HIGH, rp2.PIO.OUT_LOW, rp2.PIO.OUT_LOW),
    #out_init=(rp2.PIO.OUT_LOW),
    out_shiftdir=rp2.PIO.SHIFT_LEFT,
    autopull=True,
    pull_thresh=32,
)
def signal():
    wrap_target()
    #out(x, 3)
    #out(pins, 3)
    #out(x, 1)
    out(x, 1)
    out(pins, 3)
    wrap()
# minimum frequency is 2500    

@rp2.asm_pio(sideset_init=PIO.OUT_LOW)
def pwm_prog():
    #pull(noblock) .side(0)
    pull(noblock)
    mov(x, osr) # Keep most recent pull data stashed in X, for recycling by noblock
    mov(y, isr) # ISR must be preloaded with PWM count max
    jmp(not_x, "continue")
    #jmp("continue")
    #label("null")
    nop().side(0)
    label("continue")
    label("pwmloop")
    jmp(x_not_y, "skip")
    nop()         .side(1)
    label("skip")
    jmp(y_dec, "pwmloop")

@rp2.asm_pio(
    sideset_init=rp2.PIO.OUT_HIGH,
    out_init=rp2.PIO.OUT_HIGH,
    set_init=rp2.PIO.OUT_HIGH,
    out_shiftdir=rp2.PIO.SHIFT_RIGHT,
    autopull=True,
    #pull_thresh=32,
    #pull_thresh=4,
    #fifo_join=rp2.PIO.JOIN_TX
)
def send_data():
    #wrap_target()
    #out(pins, 1)
    label("start")
    out(x, 1)
    #nop().side(0)
    jmp(x, "a").side(0) [1]
    nop()
    set(pins, 1) [2]
    nop().side(1) [3]
    jmp("start")
    #wrap()
    label("a")
    nop()
    set(pins, 0) [2]
    nop().side(1)  [3]  
    jmp("start")
    #wrap()


sm4 = rp2.StateMachine(4, send_data, freq=100_000, sideset_base=Pin(17), out_base=Pin(18), set_base=Pin(18))

sleep(2)

class PIOPWM:
    def __init__(self, sm_id, pin, count_freq, max_count=(1 << 16) - 1):
        print(pin)
        self._sm = StateMachine(sm_id, pwm_prog, freq=2 * count_freq, sideset_base=Pin(pin))
        # Use exec() to load max count into ISR
        self._sm.put(max_count)
        self._sm.exec("pull()")
        self._sm.exec("mov(isr, osr)")
        self._sm.active(1)
        self._max_count = max_count
        self._pin = pin

    def _set(self, value):
        # Minimum value is -1 (completely turn off), 0 actually still produces narrow pulse
        if value>self._max_count:
            self._sm.active(0)
            print("off: ", value)
            Pin(self._pin, Pin.OUT).value(1)
        else:
            if not(self._sm.active()):
                self._sm.put(self._max_count)
                self._sm.exec("pull()")
                self._sm.exec("mov(isr, osr)")
                self._sm.active(1)
                print("on: ", value)
            value = max(value, -1)
            value = min(value, self._max_count)
            self._sm.put(value)
        
    def set(self, value):
        # Minimum value is -1 (completely turn off), 0 actually still produces narrow pulse
        value = max(value, -1)
        value = min(value, self._max_count)
        print(value)
        self._sm.put(value)
        
        
#PIOPWM(1, 14, pwm_prog, max_count=(1 << 16) - 1, count_freq=int(65_790))

pwm1=PIOPWM(1, 14, 65_7900)
pwm2=PIOPWM(2, 15, 65_7900)

#PIOPWM(2, 15, pwm_prog, max_count=(1 << 16) - 1, count_freq=int(657_900))

pwm1.set(int((1<<16)*0.5))
pwm2.set(int((1<<16)*0.75))

sm = rp2.StateMachine(0, signal, freq=200_000, out_base=Pin(6))

sm4.active(1)

def put_data(x):
    sm4.put(0b01111111100000011111111111111111);
    sm4.put(0b11111111111110101111111111101001);
    sm4.put(0b01001101111111111111111111111111);
    sm4.put(0b11111111111111111000000111111111);

print(sm)

p2 = Pin(16, Pin.IN, Pin.PULL_UP)
p2.irq(put_data, Pin.IRQ_FALLING)

#while True:
#    sleep(1)

# for i in range(3000):
#     print(i)
#     sleep(0.1)
#     put_data()
#     sleep(0.1)
     

# Start the StateMachine, it will wait for data on its FIFO.


d0=CHANNELS[0]
d0.CTRL_TRIG.EN = 0
d0.TRANS_COUNT = 36
d0.READ_ADDR = addressof(data)
d0.WRITE_ADDR = PIO0_BASE_TXF0
d0.CTRL_TRIG.INCR_WRITE = 0
d0.CTRL_TRIG.INCR_READ = 1
d0.CTRL_TRIG.DATA_SIZE = 2

d0.CTRL_TRIG.TREQ_SEL = 0
d0.CTRL_TRIG.CHAIN_TO = 1
#d0.CTRL_TRIG.RING_SEL = 0
#d0.CTRL_TRIG.RING_SIZE = 2

d1=CHANNELS[1]
d1.CTRL_TRIG.EN = 0
d1.TRANS_COUNT = 1
d1.READ_ADDR = addressof(ar_p)
d1.WRITE_ADDR = CH0_READ_ADDR
d1.CTRL_TRIG.INCR_WRITE = 0
d1.CTRL_TRIG.INCR_READ = 0
d1.CTRL_TRIG.DATA_SIZE = 2
d1.CTRL_TRIG.CHAIN_TO = 0


sleep(0.1)
print("on")
#Pin(16, Pin.OUT).value(1)
d1.CTRL_TRIG.EN = 1
d0.CTRL_TRIG.EN = 1
# important: start sm after channel
sm.active(1)

while True:
    sleep(1)

#sleep(2)

# if False:
#     #d0.CTRL_TRIG.EN = 0
#     d1.CTRL_TRIG.EN = 0
#     Pin(16, Pin.OUT).value(0)
#     Pin(16, Pin.OUT).value(1)
#     sleep(0.5)
#     #d0.READ_ADDR = addressof(ar)
#     #d0.TRANS_COUNT = 10
#     ar_p[0] = addressof(data2)
#     d1.READ_ADDR = addressof(ar_p)
#     d1.CTRL_TRIG.EN = 1
#     Pin(16, Pin.OUT).value(0)
#     Pin(16, Pin.OUT).value(1)
#     sleep(0.5)
# else:
#     ar_p[0] = addressof(data2)
#     SM0_CLKDIV = 0x50200000 + 0x0c8
#     MHZ_1=0b11111010000000000000000
#     MHZ_2=0b01111101000000000000000
#     KHZ_10=0b110000110101000000000000000000
#     KHZ_20=0b011000011010100000000000000000
#     mem32[SM0_CLKDIV]=MHZ_1
#     d1.READ_ADDR = addressof(ar_p)
#     sleep(0.5)
#     d1.CTRL_TRIG.EN = 0

#d0.CTRL_TRIG.EN = 0
#sm.active(0)
#print("off")
#Pin(16, Pin.OUT).value(0)

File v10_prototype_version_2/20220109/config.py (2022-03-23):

from array import array

clk_freq_list = [
    "2.5 Hz",
    "2.5 Hz",
    "2.5 Hz",
    "4.166 Hz",
    "5 Hz",
    "5 Hz",
    "6.666 Hz",
    "7.5 Hz",
    "8.215859 Hz",
    "8.333 Hz",
    "9.166 Hz",
    "10 Hz",
    "12 Hz",
    "14 Hz",
    "16 Hz",
    "17.71875 Hz",
    "18 Hz",
    "20 Hz",
    "22 Hz",
    "24 Hz",
    "26 Hz",
    "28 Hz",
    "29.71875 Hz",
    "30 Hz",
    "32 Hz",
    "34 Hz",
    "36 Hz",
    "38 Hz",
    "40 Hz",
    "41.71875 Hz",
    "42 Hz",
    "44 Hz",
    "46 Hz",
    "48 Hz",
    "50 Hz",
    "52 Hz",
    "53.71875 Hz",
    "54 Hz",
    "56 Hz",
    "58 Hz",
    "60 Hz",
    "62 Hz",
    "64 Hz",
    "65.71875 Hz",
    "66 Hz",
    "68 Hz",
    "70 Hz",
    "72 Hz",
    "74 Hz",
    "76 Hz",
    "77.71875 Hz",
    "78 Hz",
    "80 Hz",
    "82 Hz",
    "84 Hz",
    "86 Hz",
    "88 Hz",
    "89.71875 Hz",
    "90 Hz",
    "92 Hz",
    "94 Hz",
    "96 Hz",
    "98 Hz",
    "100 Hz"
]

clk_rpm_list = [
    "150.0 rpm",
    "150.0 rpm",
    "150.0 rpm",
    "249.96 rpm",
    "300 rpm",
    "300 rpm",
    "399.96 rpm",
    "450.0 rpm",
    "492.9515 rpm",
    "499.98 rpm",
    "549.96 rpm",
    "600 rpm",
    "720 rpm",
    "840 rpm",
    "960 rpm",
    "1063.125 rpm",
    "1080 rpm",
    "1200 rpm",
    "1320 rpm",
    "1440 rpm",
    "1560 rpm",
    "1680 rpm",
    "1783.125 rpm",
    "1800 rpm",
    "1920 rpm",
    "2040 rpm",
    "2160 rpm",
    "2280 rpm",
    "2400 rpm",
    "2503.125 rpm",
    "2520 rpm",
    "2640 rpm",
    "2760 rpm",
    "2880 rpm",
    "3000 rpm",
    "3120 rpm",
    "3223.125 rpm",
    "3240 rpm",
    "3360 rpm",
    "3480 rpm",
    "3600 rpm",
    "3720 rpm",
    "3840 rpm",
    "3943.125 rpm",
    "3960 rpm",
    "4080 rpm",
    "4200 rpm",
    "4320 rpm",
    "4440 rpm",
    "4560 rpm",
    "4663.125 rpm",
    "4680 rpm",
    "4800 rpm",
    "4920 rpm",
    "5040 rpm",
    "5160 rpm",
    "5280 rpm",
    "5383.125 rpm",
    "5400 rpm",
    "5520 rpm",
    "5640 rpm",
    "5760 rpm",
    "5880 rpm",
    "6000 rpm"
]

clk_div_list = array("I", [0 for _ in range(64)])

clk_div_list[0] = -0b1010110011101010011100100000000
clk_div_list[1] = -0b1010110011101010011100100000000
clk_div_list[2] = -0b1010110011101010011100100000000
clk_div_list[3] = 0b1100101101111110001011100000000
clk_div_list[4] = 0b1010100110001010110001100000000
clk_div_list[5] = 0b1010100110001010110001100000000
clk_div_list[6] = 0b111111100101100010100100000000
clk_div_list[7] = 0b111000100000111001011100000000
clk_div_list[8] = 0b110011100101111111001000000000
clk_div_list[9] = 0b110010110111100011000000000000
clk_div_list[10] = 0b101110001111100011111000000000
clk_div_list[11] = 0b101010011000101011000100000000
clk_div_list[12] = 0b100011010100100011111000000000
clk_div_list[13] = 0b11110010001100111111000000000
clk_div_list[14] = 0b11010011111011010111100000000
clk_div_list[15] = 0b10111111010111101100100000000
clk_div_list[16] = 0b10111100011000010100100000000
clk_div_list[17] = 0b10101001100010101100000000000
clk_div_list[18] = 0b10011010001000010001000000000
clk_div_list[19] = 0b10001101010010001111100000000
clk_div_list[20] = 0b10000010011010101100000000000
clk_div_list[21] = 0b1111001000110011111100000000
clk_div_list[22] = 0b1110010000110010000000000000
clk_div_list[23] = 0b1110001000001110010100000000
clk_div_list[24] = 0b1101001111101101011100000000
clk_div_list[25] = 0b1100011101110110000100000000
clk_div_list[26] = 0b1011110001100001010000000000
clk_div_list[27] = 0b1011001001110111001000000000
clk_div_list[28] = 0b1010100110001010110000000000
clk_div_list[29] = 0b1010001010001110101000000000
clk_div_list[30] = 0b1010000101110111111100000000
clk_div_list[31] = 0b1001101000100001000100000000
clk_div_list[32] = 0b1001001101101101100000000000
clk_div_list[33] = 0b1000110101001000010100000000
clk_div_list[34] = 0b1000011110100001100100000000
clk_div_list[35] = 0b1000001001101010001100000000
clk_div_list[36] = 0b111111000111110000000000000
clk_div_list[37] = 0b111110110010101101100000000
clk_div_list[38] = 0b111100100011001100000000000
clk_div_list[39] = 0b111010011101100100000000000
clk_div_list[40] = 0b111000100000110110000000000
clk_div_list[41] = 0b110110101100001011000000000
clk_div_list[42] = 0b110100111110110010100000000
clk_div_list[43] = 0b110011100110000111100000000
clk_div_list[44] = 0b110011011000000010100000000
clk_div_list[45] = 0b110001110111010101100000000
clk_div_list[46] = 0b110000011100001010000000000
clk_div_list[47] = 0b101111000110000010100000000
clk_div_list[48] = 0b101101110100100101000000000
clk_div_list[49] = 0b101100100111011010000000000
clk_div_list[50] = 0b101011101000010001000000000
clk_div_list[51] = 0b101011011110001100100000000
clk_div_list[52] = 0b101010011000101001000000000
clk_div_list[53] = 0b101001010110011110100000000
clk_div_list[54] = 0b101000010111011110000000000
clk_div_list[55] = 0b100111011011011001000000000
clk_div_list[56] = 0b100110100010000010100000000
clk_div_list[57] = 0b100101110010110011000000000
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

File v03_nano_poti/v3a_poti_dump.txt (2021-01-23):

/*
 * arduino nano v3 + 3 potentiometer
 * schliesse die drei potentiometer so an A0, A1, A2, +5V, GND
 * auf der einen seite des nano an das 0-5V an A0, A1, A2 abhaengig
 * von der stellung des potis herauskommen
 * 
 *  nullstellung, 50%, 100%
 *                \
 *     O           O           O
 *     |    ,                   \
 * 
 *  in der nullstellung sollte der wert 1 auf der konsole ausgegeben werden
 *  in der 100%-stellung sollte der wert 1023 auf der konsole ausgegeben werden
 */


/*
22:21:34.004 -> [1023, 1023, 1023]
22:21:37.494 -> [815, 1023, 1023]
22:21:38.014 -> [564, 1023, 1023]
22:21:38.524 -> [401, 1023, 1023]
*/


//int analog_a = 2; // entspricht PIN A2
//int analog_b = 1; // entspricht PIN A1
//int analog_c = 0; // entspricht PIN A0
int val_a = 0;
int val_b = 0;
int val_c = 0;
int last_a = 0;
int last_b = 0;
int last_c = 0;
int register_a = 0;
int register_b = 0;
int register_c = 0;

const boolean invert = true; // implement as macro

void setup() {
  Serial.begin(9600);
}

void loop() {
  last_a = val_a;
  last_b = val_b;
  last_c = val_c;
  val_a = analogRead(2);
  val_b = analogRead(1);
  val_c = analogRead(0);

  if (invert) {
    val_a = map(val_a,0,1023,1023,0);
    val_b = map(val_b,0,1023,1023,0);
    val_c = map(val_c,0,1023,1023,0);
  }

  /*
  if (stabilize) {
    if (abs(val_a-register_a) > 1) {
      register_a = val_a;
    }
    if (abs(val_b-register_b) > 1) {
      register_b = val_b;
    }
    if (abs(val_c-register_c) > 1) {
      register_c = val_c;
    }  
  }*/

  if (last_a != val_a || last_b != val_b || last_c != val_c) {
    Serial.print("[");
    Serial.print(val_a);
    Serial.print(", ");
    Serial.print(val_b);
    Serial.print(", ");
    Serial.print(val_c);
    Serial.print("]");
    Serial.println();
  }
  delay(500);
}

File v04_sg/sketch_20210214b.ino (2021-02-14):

/*
 * arduino nano v3 + 3 potentiometer
 * 
 * sketch_20210214b
 * 
 * aim: max kurbelwelle ~ 430 Hz ~ 25000 U/min (aber interrupt ist knapp, aber kurbelwelle ist 50-50 nicht 25-75)
 * 
 * generate two squarewave signals using timer1 (16-bit) and timer2 (8-bit)
 * check delay function
 * 
 * https://www.robotshop.com/community/forum/t/arduino-101-timers-and-interrupts/13072
 * https://www.teachmemicro.com/arduino-timer-interrupt-tutorial/
 * https://www.heise.de/developer/artikel/Timer-Counter-und-Interrupts-3273309.html
 * 
 * todos:
 * - set default values if no poties are present
 * - change settings only after period end
 * 
 */

//D12-D2 are available

#define D7 7 // timer2 isr
#define D8 8 // timer2 squarewave - lambda-sonde
#define D9 9 // timer1 isr
#define D10 10 // timer1 squarewave - kurbelwelle
#define D11 11 // loop
#define D11 11 // timer1 squarewave - nockenwelle
#define D12 12 // timer1 squarewave - zuendsignal


//volatile boolean buffer_D12;
//volatile boolean buffer_D8;

const unsigned int stability = 3;

//precalculated values for lambda-signal

//[30-10] = [177, 001->  10.016   0.016]
//3,88,87,38,38,130,171,69,38,38,113,38,11,38,184,38,69,11,38,184,99,165,25,60,85,110,131,149,164,177,
//31,36,31,20,18,25,31,12,9,8,10,6,4,4,11,3,3,2,2,5,2,3,1,1,1,1,1,1,1,1,
//   16.13,   10.69,   10.75,   13.89,   13.89,    8.00,    5.38,   11.90,   13.89,   13.89,    9.09,   13.89,   15.62,   13.89,    4.54,   13.89,   11.90,   15.62,   13.89,    4.54,    9.98,    5.76,   14.72,   12.48,   10.88,    9.28,    7.94,    6.78,    5.82,    4.99,
//    0.10,    0.13,    0.15,    0.18,    0.20,    0.25,    0.30,    0.35,    0.40,    0.45,    0.55,    0.60,    0.80,    0.90,    1.00,    1.20,    1.40,    1.60,    1.80,    2.20,    2.50,    2.89,    3.40,    4.01,    4.60,    5.39,    6.30,    7.37,    8.59,   10.02,

const byte lambda_start_timer[32] = {0,3,88,87,38,38,130,171,69,38,38,113,38,11,38,184,38,69,11,38,184,99,165,25,60,85,110,131,149,164,177};
const byte lambda_multiplier[32] = {0,31,36,31,20,18,25,31,12,9,8,10,6,4,4,11,3,3,2,2,5,2,3,1,1,1,1,1,1,1,1};
const float lambda_tick[32] = {0,16.13,   10.69,   10.75,   13.89,   13.89,    8.00,    5.38,   11.90,   13.89,   13.89,    9.09,   13.89,   15.62,   13.89,    4.54,   13.89,   11.90,   15.62,   13.89,    4.54,    9.98,    5.76,   14.72,   12.48,   10.88,    9.28,    7.94,    6.78,    5.82,    4.99};
const float lambda_predication[32] = {0,0.10,    0.13,    0.15,    0.18,    0.20,    0.25,    0.30,    0.35,    0.40,    0.45,    0.55,    0.60,    0.80,    0.90,    1.00,    1.20,    1.40,    1.60,    1.80,    2.20,    2.50,    2.89,    3.40,    4.01,    4.60,    5.39,    6.30,    7.37,    8.59,   10.02};

const boolean kurbelwelle[144] = {1,0,1,0,1,0,1,0,1,0,1,0,1,0,1,0,1,0,1,0,1,0,1,0,1,0,1,0,1,0,1,0,1,0,1,0,1,0,1,0,1,0,1,0,1,0,1,0,1,0,1,0,1,0,1,0,1,0,1,0,1,0,1,0,1,0,1,0,0,0,0,0,1,0,1,0,1,0,1,0,1,0,1,0,1,0,1,0,1,0,1,0,1,0,1,0,1,0,1,0,1,0,1,0,1,0,1,0,1,0,1,0,1,0,1,0,1,0,1,0,1,0,1,0,1,0,1,0,1,0,1,0,1,0,1,0,1,0,1,0,0,0,0,0};
const boolean zuendsignal[144] = {1,1,0,1,1,1,1,1,1,1,1,1,1,1,1,1,1,1,1,1,1,1,1,1,1,1,1,1,1,1,1,1,1,1,1,1,1,1,0,1,1,1,1,1,1,1,1,1,1,1,1,1,1,1,1,1,1,1,1,1,1,1,1,1,1,1,1,1,1,1,1,1,1,1,0,1,1,1,1,1,1,1,1,1,1,1,1,1,1,1,1,1,1,1,1,1,1,1,1,1,1,1,1,1,1,1,1,1,1,1,0,1,1,1,1,1,1,1,1,1,1,1,1,1,1,1,1,1,1,1,1,1,1,1,1,1,1,1,1,1,1,1,1,1};
const boolean nockenwelle[144] = {0,0,0,1,1,0,0,0,0,0,0,0,0,0,0,0,0,0,0,0,0,0,0,0,0,0,0,0,0,0,0,0,0,0,0,0,0,0,0,1,1,0,0,0,0,0,0,0,0,0,0,0,0,0,0,0,0,0,0,0,0,0,0,0,0,0,0,0,0,0,0,0,0,0,0,0,0,0,0,0,0,0,0,0,0,0,0,0,0,0,0,0,0,0,0,0,0,0,0,0,0,0,0,0,0,0,0,0,0,0,0,1,1,0,0,0,0,0,0,0,0,0,0,0,0,0,0,0,0,0,0,0,0,0,0,0,0,0,0,0,0,0,0,0};

// raw poti values
unsigned int val_a;
unsigned int val_b;
unsigned int val_c;

unsigned long loops;
unsigned long changes;

// raw poti values
unsigned int last_a;
unsigned int last_b;
unsigned int last_c;

// normalized poti values
unsigned int norm_a;
unsigned int norm_b;
unsigned int norm_c;

// derived values
float width_a;


// signal parameters


byte isr2_tcnt2;
byte isr2_multiplier;
boolean isr2_out_of_range;
boolean isr2_value;
//volatile ????
volatile unsigned int isr2_cnt;
unsigned int isr2_cnt_on;

unsigned int isr1_tcnt1;
unsigned int isr1_cnt;

//volatile unsigned long timer0_count = 0;
//volatile boolean hack = false;
//volatile unsigned long timer2_count = 0; //0-4294967295 (2^32 - 1)
//volatile byte timer2_byte = 0;
// hack 3
//volatile unsigned int timer2_byte = 0;
//byte lambda_dc = 0;

void setup() {
  Serial.begin(9600);
  //buffer_D12 = false;
  //buffer_D8 = false;
  
  val_a = 0;
  val_b = 0;
  val_c = 0;

  loops = 0;
  changes = 0;
  
  last_a = 0;
  last_b = 0;
  last_c = 0;

  isr1_tcnt1 = 0;
  isr1_cnt = 10;

  isr2_tcnt2 = 0;
  isr2_multiplier = 1;
  isr2_out_of_range = false;
  isr2_value = false;
  isr2_cnt = 10;
  isr2_cnt_on = 5;
  
  pinMode(D7, OUTPUT);
  pinMode(D8, OUTPUT);
  pinMode(D9, OUTPUT);  
  pinMode(D10, OUTPUT); 
  pinMode(D11, OUTPUT);
  pinMode(D12, OUTPUT);

  //timer0_count = 0;
  //timer2_count = 0;
  digitalWrite(D7, 0);
  digitalWrite(D8, 0);
  digitalWrite(D9, 0);
  digitalWrite(D10, 0);
  digitalWrite(D11, 0);
  digitalWrite(D12, 0);

  noInterrupts();           // disable all interrupts temporarily
  TCCR1A = 0;
  TCCR1B = 0;

  TCNT1 = 34286;            // Timer nach obiger Rechnung vorbelegen
  // https://www.heise.de/developer/artikel/Timer-Counter-und-Interrupts-3273309.html -> Konfiguration des Prescaler
  TCCR1B |= (1 << CS12);    // 256 als Prescale-Wert spezifizieren
  // ticks with 16us
  TIMSK1 |= (1 << TOIE1);   // Timer Overflow Interrupt aktivieren
   

  TCCR2A = 0;
  TCCR2B = 0;

  TCNT2 = 126;            // Timer nach obiger Rechnung vorbelegen
  // https://wolles-elektronikkiste.de/en/timer-and-pwm-part-1-8-bit-timer0-2 -> Setting the prescaler with the Clock Select bits for Timer2
  //TCCR2B |= (1 << CS22); TCCR2B |= (1 << CS21);    // 256 als Prescale-Wert spezifizieren
  // ticks with 16us
  TCCR2B |= (1 << CS22); TCCR2B |= (1 << CS21); TCCR2B |= (1 << CS20);   // 1024 als Prescale-Wert spezifizieren
  // ticks with 64us
  TIMSK2 |= (1 << TOIE2);   // Timer Overflow Interrupt aktivieren  
  
  interrupts();             // activate all interrupts
}


ISR(TIMER1_OVF_vect)          // timer1 overflow interrupt service routine
{
  //TCNT1 = 34286; 
  //TCNT1 = 0; // expected 1048.576 ms
  //TCNT1 = 0; // expected 1048.576 ms
  TCNT1 = 65536-16384; // expected 262.144 ms 
  TCNT1 = 65536-1024; // expected 16.384 ms
  TCNT1 = 65536-32; // expected 0.512 ms
  TCNT1 = 65536-4; // expected 0.064 ms
  TCNT1 = 65536-2; // expected 0.032 ms
  digitalWrite(D9, 1);
  digitalWrite(D10, kurbelwelle[isr1_cnt]);
  digitalWrite(D11, nockenwelle[isr1_cnt]);
  digitalWrite(D12, zuendsignal[isr1_cnt]);
  //digitalWrite(D12, digitalRead(D12) ^ 1);
  isr1_cnt++;
  if (isr1_cnt >= 144) {
    isr1_cnt = 0;
  }
  digitalWrite(D9, 0);
}
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

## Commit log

2020-07-21 version 1 running on board 4/5 error
2021-02-21 fixed bug with two long 0-period
    [20210221a.py]
2021-03-13 added PWM example for lambda sonde
2021-05-25 playback of three signals is ready
    - clock divider register can be used to change frequency, add waits in sm if to fast
    - playback array can be switched via start address of dma channel 1
    - failed zuendung in 5% steps can be achieved by bigger playback array
    [20210525a_dma_channel_switching_payload.py]
2021-05-25 pwm signal with 0.1 Hz
2021-06-03 added diagram for gears
2021-06-03 fixed igf gear
2021-07-31 new files enclosure for potis
    [enclosure_potis_v1.scad]
2021-07-31 completed poties
    [Pico_MCP3008.fzz]
2021-08-08 todo: stabilize on each channel individually
    [simulator.py]
2021-12-29 added warning regarding small holes for poties
    [enclosure_potis_v1.scad]
2022-01-16 cross compiled on debian using readme.md in ports/windows and google "lookslikematrix micropython raspberry pi"
2022-01-30 r9: misc added pwm via hack
2022-02-25 added igf switches
2022-03-19 renamed directories
    [Pico_MCP3008.fzz, enclosure.scad, enclosure_potis_v1.scad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]
2022-09-13 added code and screenshots regarding signal approximation
    [control_points.xlsx, control_points_2.xls]
2022-09-14 added first script to stream signal with 960 samples at 10kHz on parallel interface
